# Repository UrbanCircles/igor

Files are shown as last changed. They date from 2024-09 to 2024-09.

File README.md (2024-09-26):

# Project IGOR - open-source, offline, loyal, cheerful, focus assistant

A simple, tactile tool to help you track and hopefully increase the amount of minutes that matter each day.

This project is designed to help you stay on track with your focus sessions, using a simple and intuitive interface via a rotary encoder and an OLED display. Whether you need to time focused work, breaks or other worthy pursuits, this simple cheerful timer is a perfect tool to support your productivity.

Bonus: it's cheap to put together and highly hackable. I wrote the code in a modular way and you can add your own functions to it easily. Just make sure you share that back so that we can all enjoy your ideas in action!!

## Its simple features (v1)

- **Up and Down Counting Modes:** Select either *count up* or *count down* mode. Both are in minutes based on millies (seconds seem way too distracting - you want to slow down and dive in).
- **Rotary Encoder Control:** Use the encoder to navigate the menu and adjust timer values. Rotate to move up and down, click to confirm. Easy.
- **OLED Display:** Provides real-time feedback on timer status and focus session duration, as well as your beautiful Flow total minutes acculturated since your last reset.
- **IDLE Mode:** Automatically enters *IDLE mode* after 3 minutes of inactivity (and shows up a question to prompt you to come back into action), turns off the display after 30 minutes to conserve energy.
- **Success Animation:** Displays a short animation at the end of each session (positive reinforcement gains!).
- **Manual Timer Reset:** Reset your total focus time using a simple menu option so you can start afresh. Unplugging the device also achieves this - nothing is permanent, we have to keep performing!
- **Cute hats that you can swap:** Design your own rotary encoder knobs, ney - hats, or download some that I made. Add some personality to your assistant, be it a British butler, a French concierge, or Italian enforcer, etc. have some fun with this. And make sure you give it a name.

_DSC0945 Large

## BOM

- Adafruit SSD1306 OLED Display (128x64)
- KY-040 rotary encoder
- D1 mini board (any Arduino board will do, but you will have to adjust the sketch)
- 3D printer for the shell - all pressure fit, no screws, no glue, nothing else required

## Pinout

| Component | Pin |
|---|-----|
| OLED SDA | A4  |
| OLED SCL | A5  |
| Rotary Encoder CLK | D6  |
| Rotary Encoder DT | D7  |
| Rotary Encoder SW | D4  |

## Microcontroller firmware

One sketch file, using the IDE of your choice (e.g. the main Arduino IDE works well with the added modules for D1 mini + libraries - that's what I use).  
Please check everything is working before soldering and squeezing everything into the 3D printed shell.

## Assembly

There are only 3 components to this:

- The shell - the D1 mini fits snuggly in there, and the rotary encoder screws on the top.
- The faceplate - the OLED slides in (make sure the display is nicely squared - the slide should allow some wiggle room, as the tolerances on these displays are quite bad but hey, it's really cheap).
- The hat - this is the knob to rotate and press on. It fits on top of the rotary encoder, with the key as a guide.

The orientation of parts on the printer's bed matters - only some hats will need internal supports because of the interface with the rotary encoder. All else prints easily with normal PLA (but you can get more exotic - people share your creations!).

Do play with the dimensions - tolerances (around 0.2-0.3mm) work very well for our printers and achieve a satisfying fit, but they require some adjustment/scaling for your setup.

The order of the assembly I found to work best is:

1. First, wire everything together, write the firmware to the board, fire it up, rotate, click, play - make sure everything works well. Do not use headers for the D1 mini, check the length of your wires and the orientation of components - it's a tight but precise fit.
2. Second, the OLED panel should be attached to the faceplate.
3. Third, the rotary encoder and the D1 mini (which only goes in one way) should be attached to the shell.
4. Lastly, you can snap everything together.

Note on hats: I encourage you to make this your own by designing and printing (and hopefully sharing) a custom hat. The dimensions to fit the encoder are openly available online and it's really simple to put something together. I have made available several iteration that I found funny or relevant as I was dressing up my assistant - you only need one.

## User Guide

### How to Use

#### 1. Initial Setup

When powered on, the device will start in the main menu. The top of the screen displays your total focus time, while the main menu shows the current option to select (UP, DOWN, or Reset). The rotary encoder allows you to scroll through the options and make selections with a button press.  
Basically, there is no initial setup... we're ready when you are!

#### 2. Main Menu

The main menu offers three options:

- **UP:** Start counting focus time upward. Great for open-ended focus sessions.
- **DOWN:** Select a countdown duration and track your focus session as it counts down to zero.
- **Reset:** Manually reset your total focus time to zero. This won't affect current sessions but will clear the accumulated flow minutes shown on the top of the screen.

#### 3. Count UP Mode

- Rotate to the **UP** option and click the button to start.
- The display shows "Focus!" with an upward-pointing triangle, and the elapsed minutes appear in large text.
- Click the button again to stop and return to the menu. The session's duration is added to your total focus time.

#### 4. Count DOWN Mode

- Rotate to the **DOWN** option and click the button.
- Use the encoder to adjust the countdown duration, then click again to start the countdown.
- The display shows "Focus!" with a downward-pointing triangle, and the remaining minutes appear in large text.
- When the countdown reaches zero, a success animation is displayed, and the time is added to your total focus time.

#### 5. Reset Focus Time

From the menu, rotate to the **Reset** option and click the button to reset your total focus time to zero.

#### 6. IDLE Mode

If the timer remains in the menu or selection screen without user interaction for more than 3 minutes, the display will show "IDLE?" - this is purely to taunt you back into action!  
After 30 minutes of inactivity, the display turns off entirely - this is to conserve energy.  
Simply press the button to exit IDLE mode and return to the menu.

### Example Workflow

- Select **UP** to start timing a work session.
- After completing the session, stop the timer, and your total focus time is updated.
- Next, select **DOWN** to time a 20-minute break by adjusting the countdown timer.
- At the end of the day, if you want to reset your total focus time, navigate to **Reset** and click the button to start fresh.

## Roadmap ideas

Here are a bunch of features I think might be cool to try out. Please add your ideas as well. Also, please help me by submitting code!! I'm a designer, not a programmer and could really use some of your talents to bring this project alive.

- [ ] Add sound notifications
- [ ] Get internet time via Wifi + portal, since this is a ESP module
- [ ] More animations and transitions
- [ ] More modes available (any ideas?)
- [ ] API to interact with external applications (e.g. Time trackers, ToDo apps, Shortcuts/ automations)

## Disclaimer

I've done my best to document everything accurately - however, there might be mistakes. If you see them, or opportunities to improve, please open an issue.  
This is an open-source project given for free, with no warranties or guarantees. It assumes a level of proficiency with electronics, assemblies, engineering, etc. Stay safe. Stay productive. Work with what you have. Make the world a better place.

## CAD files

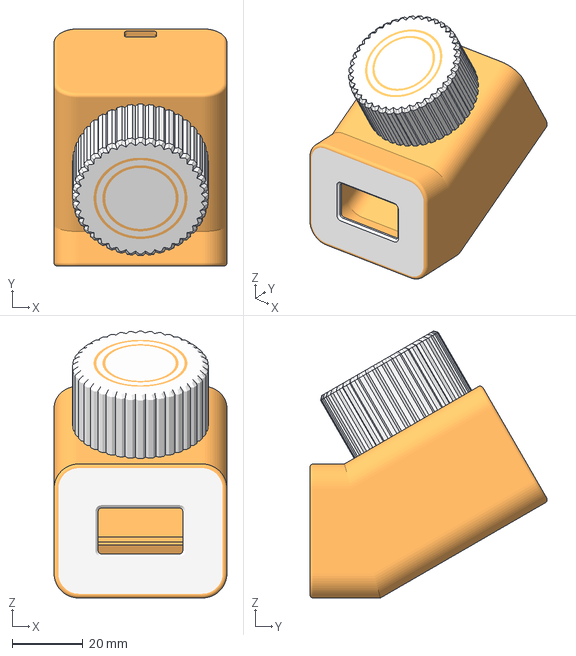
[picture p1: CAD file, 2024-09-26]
3D Parts/Project IGOR v1 - shell, faceplate, basic hat.3mf
49.0 x 67.3 x 75.7 mm

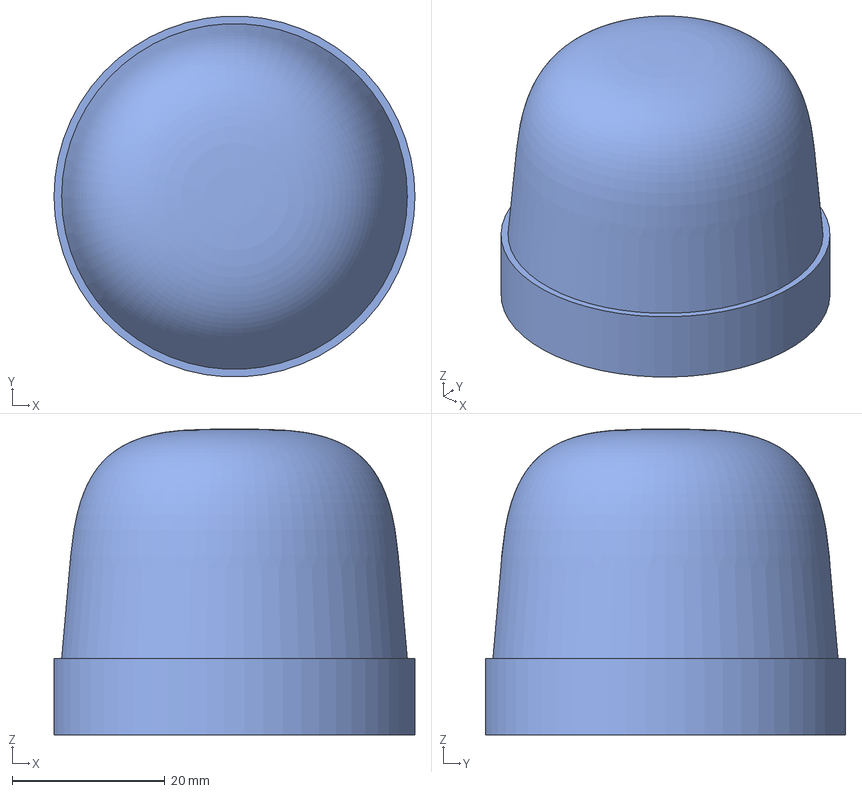
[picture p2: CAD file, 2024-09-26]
3D Parts/Other Hats.3mf
47.2 x 47.2 x 40.0 mm

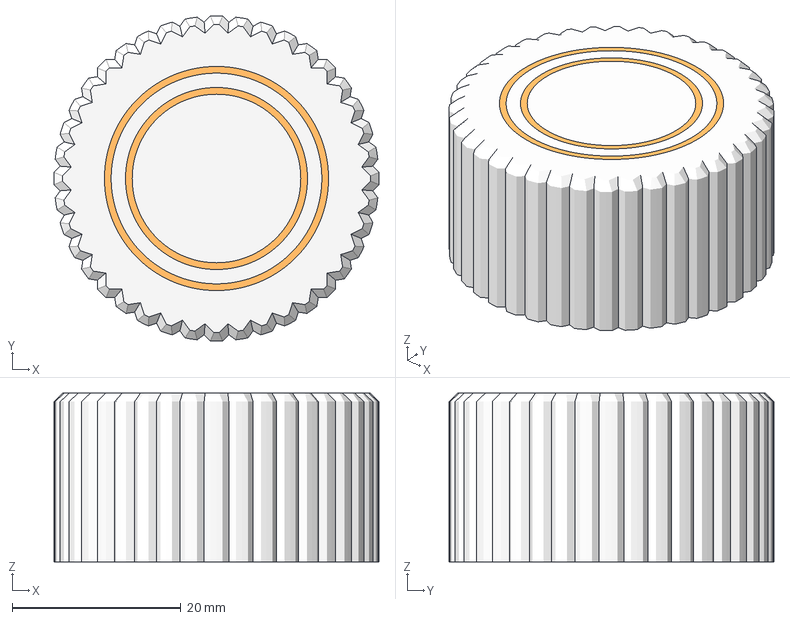
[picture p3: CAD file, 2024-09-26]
3D Parts/Basic Hat only.3mf
38.6 x 38.6 x 20.0 mm
classic
small groove
big groove

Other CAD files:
3D Parts/Project IGOR v1 - shell, faceplate, basic hat (STEP).step

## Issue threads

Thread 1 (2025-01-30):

Could I replace the D1 mini with the NodeMCU (CH340) ?

Eyadserry, 2025-01-30:
without changing the code.

CrazyPyro, 2025-02-17:
I would think so.  I have the author's suggested part and it shows up as "ch341-uart" when I plug it in.
Just check your datasheet for what signals are on which pins - Probably the biggest "code change" you'd need is to tweak the define's at the top to match your pins: https://github.com/UrbanCircles/igor/blob/main/sketch_sep25a.ino#L8-L10

Closed 2025-02-22.

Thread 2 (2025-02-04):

Front panel mounting holes don't line up with display

ami-levin, 2025-02-04:
Hi,
First, thank you for this lovely project and for sharing it with the community.
I printed the files as-is with no scaling and ordered the display using your affiliate links, but the mounting holes don't line up as you can see in the attached photos.
Not sure what the issue is, but I thought you'd like to know about it.
Have a great day!

[](url)

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

t-shtipkov, 2025-02-09:
Hello, I had a similar issue you can check this:
https://www.printables.com/model/1184893-igor-faceplate

b2solutions, 2025-02-13:
Dang, didn't see this until now. Copious amounts of hot glue was my solution. Thanks for posting.

UrbanCircles, 2025-02-22:
we added the extra STL to solve this.

Closed 2025-02-22.

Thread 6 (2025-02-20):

Display not initialized correctly

NullNullZero, 2025-02-20:
Display didn't work, the error was in this line:

`Adafruit_SSD1306 display(128, 64, &Wire, D4);`

Changed D4 to -1, works now

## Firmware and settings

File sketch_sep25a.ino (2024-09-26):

#include <Wire.h>
#include <Adafruit_SSD1306.h>

//-----------------------------------------------
Adafruit_SSD1306 display(128, 64, &Wire, D4);

//-----------------------------------------------
#define CLK    D6
#define DT     D7
#define SW     D4

//-----------------------------------------------
int flowMinutes = 0;   // Total flow minutes
int menuIndex = 0;     // 0 for UP, 1 for DOWN, 2 for Reset
String menuOptions[3] = {"UP", "DOWN", "Reset"};  // Label reset option as "Reset"
unsigned long lastActivityTime = 0;  // For inactivity detection
const unsigned long inactivityLimit = 3 * 60000;  // 3 minutes in milliseconds

enum State { MENU, COUNTING_UP, COUNTING_DOWN, SELECTING_DOWN_DURATION, IDLE };
State currentState = MENU;

int countdownValue = 20;  // Default value for countdown
int initialCountdownValue = 20;  // Store the countdown value when selected
unsigned long previousMillis = 0;  // For counting logic
int elapsedMinutes = 0;
bool isCounting = false;
unsigned long buttonDebounceTime = 0;
const unsigned long buttonDebounceDelay = 800;  // Debounce delay

// Rotary encoder debounce variables
unsigned long lastRotaryTime = 0;
const unsigned long rotaryDebounceDelay = 150;  // Faster debounce for rotary encoder

// IDLE mode extended behavior
const unsigned long displayOffTimeLimit = 30 * 60000;  // 30 minutes in milliseconds

unsigned long idleStartTime = 0;  // Track when IDLE mode starts
bool displayOff = false;  // Track if the display is off

//=========================================================
void setup() {  
  initHardware();
  initDisplay();
  updateDisplay();
  Serial.println("Setup complete, starting loop...");
}

//=========================================================
void loop() {
  unsigned long currentMillis = millis();
  
  // Handle rotary encoder input
  handleRotaryInput();

  // Handle button presses and states
  handleButtonPresses(currentMillis);

  // Handle counting logic
  handleCounting(currentMillis);

  // Handle inactivity
  handleInactivity(currentMillis);
}

//=========================================================
// Initialize hardware pins and serial communication
void initHardware() {
  pinMode(CLK, INPUT);
  pinMode(DT, INPUT);
  pinMode(SW, INPUT);
  Serial.begin(9600);
}

//=========================================================
// Initialize the OLED display
void initDisplay() {
  if (!display.begin(SSD1306_SWITCHCAPVCC, 0x3C)) {
    Serial.println(F("SSD1306 allocation failed"));
    for (;;);
  }
  display.clearDisplay(); 
  Serial.println("Display initialized.");
}

//=========================================================
// Update the OLED display with the current state
void updateDisplay() {
  display.setTextColor(WHITE);
  display.clearDisplay();

  // Display top row
  String topRowText;
  
  if (currentState == COUNTING_UP) {
    topRowText = "Focus! \x18";  // Focus with upward triangle for counting UP
  } else if (currentState == COUNTING_DOWN) {
    topRowText = "Focus! \x19";  // Focus with downward triangle for counting DOWN
  } else {
    topRowText = "Flow: " + String(flowMinutes);  // Display total flow minutes when not counting
  }

  int topRowTextWidth = topRowText.length() * 12;  // TextSize 2, so 12 pixels per char
  int topRowX = (128 - topRowTextWidth) / 2;  // Center the text on the top row

  display.setTextSize(2);  // Larger size for top row
  display.setCursor(topRowX, 0);  // Centered on top row
  display.print(topRowText);

  // Display main row (menu or counting values)
  String mainRowText;
  
  if (currentState == MENU) {
    mainRowText = menuOptions[menuIndex];  // Display UP, DOWN, or Reset in the menu
  } else if (currentState == COUNTING_UP) {
    mainRowText = String(elapsedMinutes);  // Display counting up minutes
  } else if (currentState == COUNTING_DOWN || currentState == SELECTING_DOWN_DURATION) {
    mainRowText = String(countdownValue);  // Display countdown minutes
  } else if (currentState == IDLE) {
    mainRowText = "IDLE?";
  }
  
  int mainRowTextWidth = mainRowText.length() * 24;  // TextSize 4, so 24 pixels per char
  int mainRowX = (128 - mainRowTextWidth) / 2;  // Calculate centered X position

  display.setTextSize(4);  // Larger size for main row
  display.setCursor(mainRowX, 30);  // Centered on main row
  display.print(mainRowText);
  
  display.display();  // Show the updated display
}

//=========================================================
// Detect button presses with debounce logic
bool buttonPressed() {
  if (digitalRead(SW) == LOW && (millis() - buttonDebounceTime > buttonDebounceDelay)) {
    buttonDebounceTime = millis();  // Debounce
    lastActivityTime = millis();  // Reset inactivity timer
    return true;
  }
  return false;
}

//=========================================================
// Handle button presses and manage state transitions
void handleButtonPresses(unsigned long currentMillis) {
  if (!buttonPressed()) return;

  switch (currentState) {
    case MENU:
      if (menuIndex == 0) {  // UP selected
        startCountingUp();
      } else if (menuIndex == 1) {  // DOWN selected
        startSelectingDownDuration();
      } else if (menuIndex == 2) {  // Reset selected
        resetFlowMinutes();  // Reset the total focus time to 0
      }
      break;
      
    case SELECTING_DOWN_DURATION:
      confirmCountdownSelection();
      break;

    case COUNTING_UP:
      stopCountingUp();
      break;

    case COUNTING_DOWN:
      stopCountingDown();
      break;
  }
  updateDisplay();
}

//=========================================================
// Start counting up
void startCountingUp() {
  currentState = COUNTING_UP;
  elapsedMinutes = 0;
  isCounting = true;
  lastActivityTime = millis();  // Reset inactivity timer
  Serial.println("Counting UP started.");
}

//=========================================================
// Start selecting the countdown duration
void startSelectingDownDuration() {
  currentState = SELECTING_DOWN_DURATION;
  countdownValue = 20;
  lastActivityTime = millis();  // Reset inactivity timer
  Serial.println("Selecting DOWN duration.");
}

//=========================================================
// Confirm countdown selection and start counting down
void confirmCountdownSelection() {
  initialCountdownValue = countdownValue;
  currentState = COUNTING_DOWN;
  isCounting = true;
  lastActivityTime = millis();  // Reset inactivity timer
  Serial.print("Counting DOWN started with "); Serial.print(countdownValue); Serial.println(" minutes.");
}

//=========================================================
// Stop counting up and return to menu
void stopCountingUp() {
  flowMinutes += elapsedMinutes;
  successAnimation();
  currentState = MENU;
  isCounting = false;
  Serial.println("Counting UP stopped. Returning to MENU.");
}

//=========================================================
// Stop counting down and return to menu
void stopCountingDown() {
  flowMinutes += (initialCountdownValue - countdownValue);
  successAnimation();
  currentState = MENU;
  isCounting = false;
  Serial.println("Counting DOWN stopped. Returning to MENU.");
}

//=========================================================
// Reset the total flow minutes counter to 0
void resetFlowMinutes() {
  flowMinutes = 0;
  Serial.println("Flow minutes reset to 0.");
  updateDisplay();  // Update the display to show the reset value
}

//=========================================================
// Handle counting up or down logic
void handleCounting(unsigned long currentMillis) {
  if (!isCounting || (currentMillis - previousMillis < 60000)) return;

  previousMillis = currentMillis;
  
  if (currentState == COUNTING_UP) {
    elapsedMinutes++;
    updateDisplay();
    Serial.print("Counting UP: "); Serial.println(elapsedMinutes);
  } else if (currentState == COUNTING_DOWN) {
    countdownValue--;
    if (countdownValue <= 0) {
      flowMinutes += initialCountdownValue;
      successAnimation();
      currentState = MENU;
      isCounting = false;
      Serial.println("Countdown finished, returning to MENU.");
    }
    updateDisplay();
    Serial.print("Counting DOWN: "); Serial.println(countdownValue);
  }
}

//=========================================================
// Success animation when a session ends
void successAnimation() {
  display.clearDisplay();
  int centerX = 64, centerY = 32;

  for (int radius = 2; radius <= 30; radius += 2) {
    display.drawCircle(centerX, centerY, radius, WHITE);
    display.display();
    delay(100);

    if (radius % 4 == 0) {
      display.clearDisplay();
      display.display();
      delay(2);
    }
  }
  
  display.clearDisplay();
  display.setTextSize(2);
  display.setCursor(20, 20);
  display.print("SUCCESS!");
  display.display();
  delay(1000);
  display.clearDisplay();
  display.display();
}

//=========================================================
// Rotary Encoder Rotation Detection
int getRotation() {
  static int previousCLK = digitalRead(CLK);
  int currentCLK = digitalRead(CLK);
  
  if (currentCLK == LOW && previousCLK == HIGH && (millis() - lastRotaryTime > rotaryDebounceDelay)) {
    lastRotaryTime = millis();  // Debounce
    int DTValue = digitalRead(DT);  // Read DT to determine direction

    previousCLK = currentCLK;  // Update previous CLK for next iteration

    return (DTValue != currentCLK) ? 1 : -1;  // Clockwise or counterclockwise
  }
  
  previousCLK = currentCLK;
  return 0;  // No rotation
}

//=========================================================
// Handle rotary input for menu and countdown selection
void handleRotaryInput() {
  int rotation = getRotation();
  if (rotation == 0) return;  // No rotation detected
  
  lastActivityTime = millis();  // Reset inactivity timer on any valid rotation
  Serial.print(millis());  // Print the current time in milliseconds
  Serial.print(" - Rotation detected, activity timer reset. Rotation: ");
  Serial.println(rotation);

  if (currentState == MENU) {
    menuIndex = (menuIndex + rotation + 3) % 3;  // Update for 3 menu options: UP, DOWN, Reset
    updateDisplay();
    Serial.print(millis());  // Print the current time in milliseconds
    Serial.print(" - Menu option: "); Serial.println(menuOptions[menuIndex]);
  } else if (currentState == SELECTING_DOWN_DURATION) {
    countdownValue = max(1, countdownValue + rotation);
    updateDisplay();
    Serial.print(millis());  // Print the current time in milliseconds
    Serial.print(" - Countdown value: "); Serial.println(countdownValue);
  }
}
//=========================================================
// Handle inactivity and switch to IDLE if necessary
void handleInactivity(unsigned long currentMillis) {
  // Comment out frequent serial prints to improve performance
  /*
  Serial.print(millis());
  Serial.print(" - Current time (millis): ");
  Serial.println(currentMillis);
  
  Serial.print(millis());
  Serial.print(" - Last activity time (millis): ");
  Serial.println(lastActivityTime);
  */

  // Make sure the subtraction does not cause an overflow/underflow
  if (currentMillis >= lastActivityTime) {
    unsigned long timeSinceLastActivity = currentMillis - lastActivityTime;

    /*
    Serial.print(millis());
    Serial.print(" - Time since last activity (ms): ");
    Serial.println(timeSinceLastActivity);
    */

    // Check if the user is in the MENU or selecting countdown duration mode
    if ((currentState == MENU || currentState == SELECTING_DOWN_DURATION) && 
        (timeSinceLastActivity > inactivityLimit)) {
      if (currentState != IDLE) {
        currentState = IDLE;
        idleStartTime = millis();  // Record when IDLE mode starts
        updateDisplay();
        Serial.print(millis());  // Print the current time in milliseconds
        Serial.println(" - IDLE state entered due to inactivity.");
      }
    }
  } else {
    // Comment out warning to reduce unnecessary serial prints
    // Serial.println(" - Warning: currentMillis is less than lastActivityTime!");
  }

  // Check if the user has been in IDLE for more than 30 minutes and turn off the display
  if (currentState == IDLE && !displayOff && (currentMillis - idleStartTime > displayOffTimeLimit)) {
    displayOff = true;
    display.ssd1306_command(SSD1306_DISPLAYOFF);  // Turn off the display
    Serial.print(millis());  // Print the current time in milliseconds
    Serial.println(" - Display turned off after 30 minutes of IDLE.");
  }

  // Exit IDLE if any rotary or button action happens
  if (currentState == IDLE && (getRotation() != 0 || buttonPressed())) {
    currentState = MENU;
    lastActivityTime = millis();  // Reset inactivity timer upon exiting IDLE
    
    // Turn the display back on if it was off
    if (displayOff) {
      display.ssd1306_command(SSD1306_DISPLAYON);
      displayOff = false;
      Serial.print(millis());  // Print the current time in milliseconds
      Serial.println(" - Display turned back on.");
    }

    updateDisplay();
    Serial.print(millis());  // Print the current time in milliseconds
    Serial.println(" - Exiting IDLE mode. Back to MENU.");
  }
}

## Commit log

2024-09-25 Create 3D Print Files
2024-09-27 Rename Project IGOR v1 - shell, faceplate, basic hat to Project IGOR v1 - shell, faceplate, basic hat.3mf
    [Project IGOR v1 - shell, faceplate, basic hat.3mf]
